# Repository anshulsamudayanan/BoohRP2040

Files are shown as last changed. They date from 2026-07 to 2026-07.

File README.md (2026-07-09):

# Booh RP2040

A minimal, RP2040-based Pi Pico clone, designed and built from scratch in KiCad.



## Overview

Booh RP2040 is a custom development board built around the Raspberry Pi RP2040 microcontroller.This repo covers schematic capture, PCB layout, and assembly for a minimal Pico-style board.

## Specs

- **MCU:** Raspberry Pi RP204
- **Flash:** W25Q16JV, 2MB QSPI flash
- **Power:** USB-C input, regulated to 3.3V via onboard LDO
- **I/O:** through-hole pin headers along both edges
- **Layout:** 2-layer PCB with groud layer
- **Form factor:** Pi Pico-sized footprint

## Repo Contents

- `kicad/` — KiCad schematic and PCB layout files
- `gerbers/` — Gerber files for manufacturing
- `bom/` — Bill of materials

## Getting Started

1. Order the PCB using the Gerber files in `gerbers/` (JLCPCB, PCBWay, etc.)
2. Source components using the BOM in `bom/`
3. Assemble and Solder by hand to obtain new skillz
4. Flash with MicroPython, CircuitPython, or the Pico SDK like a standard RP2040 board

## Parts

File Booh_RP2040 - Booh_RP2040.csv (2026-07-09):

Id | Designator | Footprint | Quantity | Designation | Supplier and ref
1 | C1, C2, C3, C4, C5, C6, C7, C8, C10, C11, C17 | C_0402_1005Metric | 11 | 0.1uF | Aliexpress
2 | C9, C12 | C_0402_1005Metric | 2 | 1uF | Aliexpress
3 | C13, C14 | C_0603_1608Metric | 2 | 10uF | Aliexpress
4 | C15, C16 | C_0402_1005Metric | 2 | 15pF | Aliexpress
5 | J1 | USB_C_Receptacle_HRO_TYPE-C-31-M-12 | 1 | USB_C_Receptacle_USB2.0_14P | Aliexpress
6 | J2, J3 | PinHeader_1x20_P2.54mm_Vertical | 2 | Conn_01x20 | Aliexpress
7 | J4 | PinHeader_1x03_P2.54mm_Vertical | 1 | Conn_01x03 | Aliexpress
8 | R1, R2 | R_0402_1005Metric | 2 | 5.1K | Aliexpress
9 | R3, R4 | R_0402_1005Metric | 2 | 27K | Aliexpress
10 | R5, R6 | R_0402_1005Metric | 2 | 1K | Aliexpress
11 | R7 | R_0402_1005Metric | 1 | 10K | Aliexpress
12 | SW1 | SW_Push_SPST_NO_Alps_SKRK | 1 | SW_Push | Aliexpress
13 | U1 | QFN-56-1EP_7x7mm_P0.4mm_EP3.2x3.2mm | 1 | RP2040 | Aliexpress
14 | U3 | Winbond_USON-8-1EP_3x2mm_P0.5mm_EP0.2x1.6mm | 1 | W25Q128JVS | Aliexpress
15 | U4 | SOT-23 | 1 | MCP1700x-330xxTT | Aliexpress
16 | Y1 | Crystal_SMD_3225-4Pin_3.2x2.5mm | 1 | 12 MHz | Aliexpress
17 | - | Solder Iron | 1 | Pinecil V1 | Aliexpress
18 | - | Flux Paste | 1 | Flux Paste | Aliexpress
19 | - | Brass Sponge | 1 | to Clean | Aliexpress
20 | - | Solder Wire | 1 | wire | Aliexpress
21 | - | PCB | 1 | PCB | pcbway

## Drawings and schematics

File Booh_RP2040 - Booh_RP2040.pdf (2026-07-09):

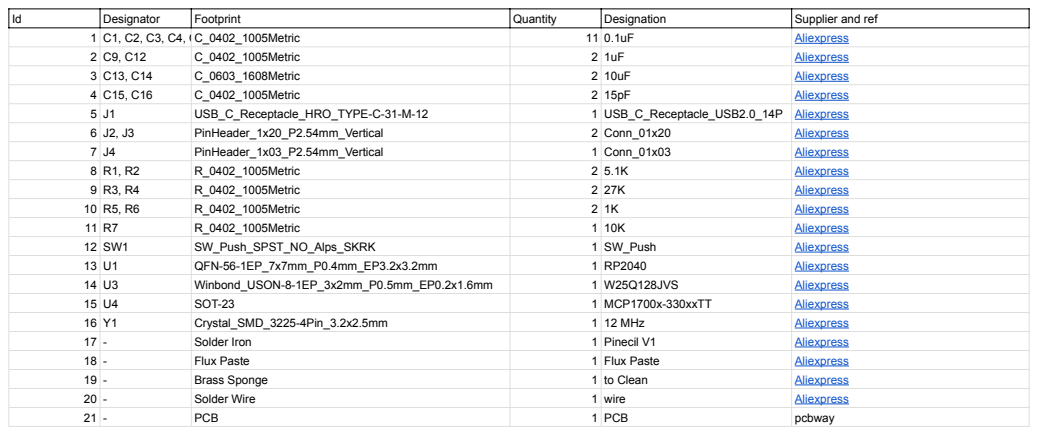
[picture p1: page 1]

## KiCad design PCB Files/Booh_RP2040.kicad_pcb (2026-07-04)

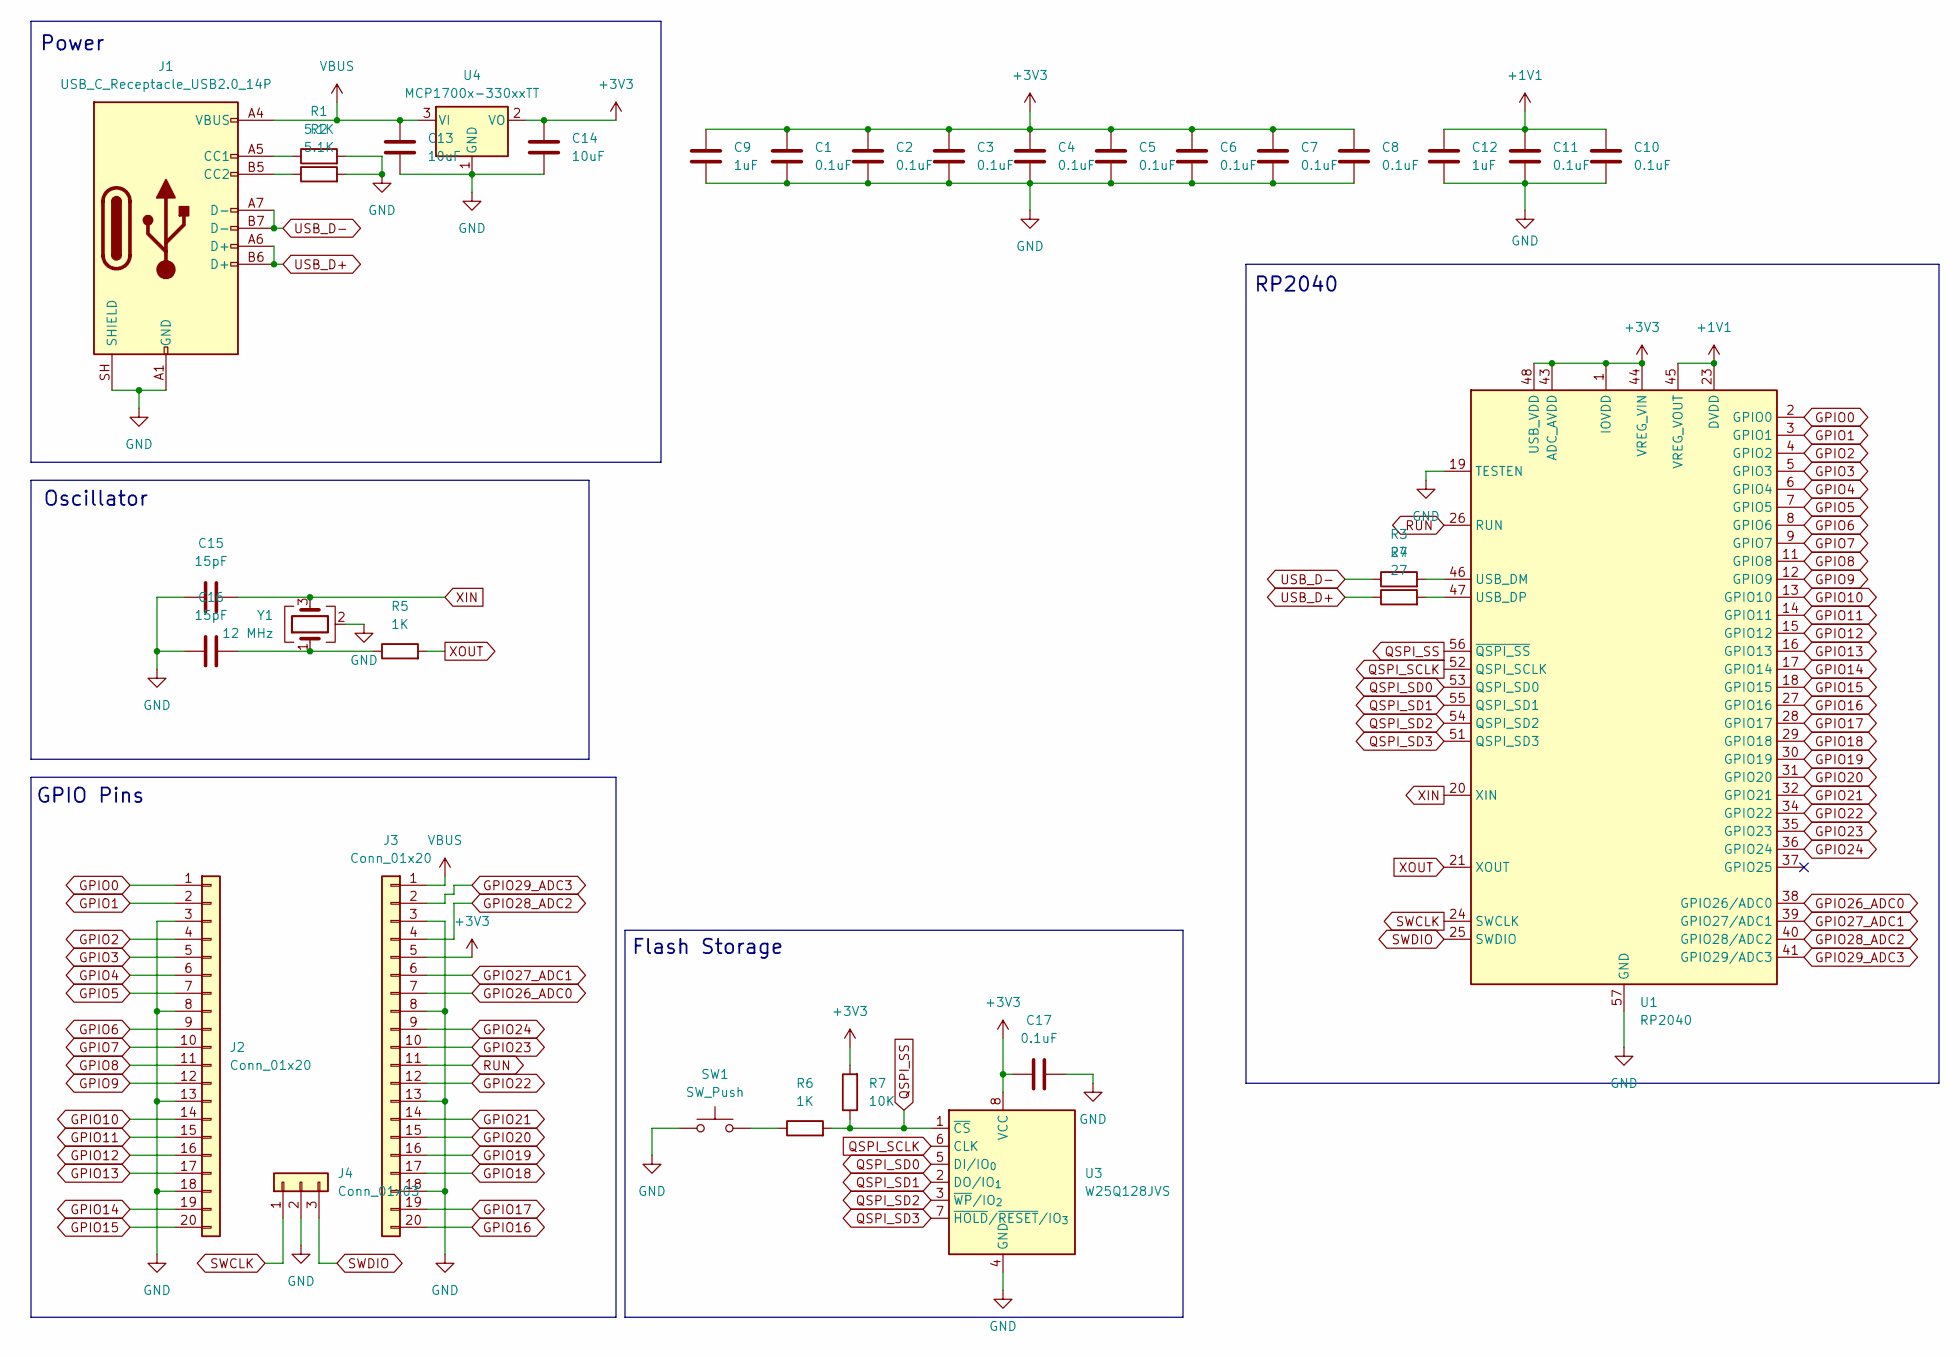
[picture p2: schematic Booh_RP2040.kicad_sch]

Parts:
C1, C2, C3, C4, C5, C6, C7, C8, C10, C11, C17: 0.1uF; C_0402_1005Metric
C9, C12: 1uF; C_0402_1005Metric
C13, C14: 10uF; C_0603_1608Metric
C15, C16: 15pF; C_0402_1005Metric
J1: USB_C_Receptacle_USB2.0_14P; USB_C_Receptacle_HRO_TYPE-C-31-M-12
J2, J3: Conn_01x20; PinHeader_1x20_P2.54mm_Vertical
J4: Conn_01x03; PinHeader_1x03_P2.54mm_Vertical
R1, R2: 5.1K; R_0402_1005Metric
R3, R4: 27; R_0402_1005Metric
R5, R6: 1K; R_0402_1005Metric
R7: 10K; R_0402_1005Metric
SW1: SW_Push; SW_Push_SPST_NO_Alps_SKRK
U1: RP2040; QFN-56-1EP_7x7mm_P0.4mm_EP3.2x3.2mm
U3: W25Q128JVS; Winbond_USON-8-1EP_3x2mm_P0.5mm_EP0.2x1.6mm
U4: MCP1700x-330xxTT; SOT-23
Y1: 12 MHz; Crystal_SMD_3225-4Pin_3.2x2.5mm

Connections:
+1V1: C10.1, C11.1, C12.1, U1.23 (DVDD), U1.45 (VREG_VOUT), U1.50 (DVDD)
+3V3: C1.1, C2.1, C3.1, C4.1, C5.1, C6.1, C7.1, C8.1, C9.1, C14.1, C17.1, J3.5, R7.2, U1.1 (IOVDD), U1.10 (IOVDD), U1.22 (IOVDD), U1.33 (IOVDD), U1.42 (IOVDD), U1.43 (ADC_AVDD), U1.44 (VREG_VIN), U1.48 (USB_VDD), U1.49 (IOVDD), U3.8 (VCC), U4.2 (VO)
GND: C1.2, C2.2, C3.2, C4.2, C5.2, C6.2, C7.2, C8.2, C9.2, C10.2, C11.2, C12.2, C13.2, C14.2, C15.1, C16.1, C17.2, J1.A1 (GND), J1.A12 (GND), J1.B1 (GND), J1.B12 (GND), J1.SH (SHIELD), J2.3, J2.8, J2.13, J2.18, J3.3, J3.8, J3.13, J3.18, J4.2, R1.2, R2.2, SW1.1, U1.19 (TESTEN), U1.57 (GND), U3.4 (GND), U4.1 (GND), Y1.2 (G), Y1.4 (G)
GPIO0: J2.1, U1.2 (GPIO0)
GPIO1: J2.2, U1.3 (GPIO1)
GPIO2: J2.4, U1.4 (GPIO2)
GPIO3: J2.5, U1.5 (GPIO3)
GPIO4: J2.6, U1.6 (GPIO4)
GPIO5: J2.7, U1.7 (GPIO5)
GPIO6: J2.9, U1.8 (GPIO6)
GPIO7: J2.10, U1.9 (GPIO7)
GPIO8: J2.11, U1.11 (GPIO8)
GPIO9: J2.12, U1.12 (GPIO9)
GPIO10: J2.14, U1.13 (GPIO10)
GPIO11: J2.15, U1.14 (GPIO11)
GPIO12: J2.16, U1.15 (GPIO12)
GPIO13: J2.17, U1.16 (GPIO13)
GPIO14: J2.19, U1.17 (GPIO14)
GPIO15: J2.20, U1.18 (GPIO15)
GPIO16: J3.20, U1.27 (GPIO16)
GPIO17: J3.19, U1.28 (GPIO17)
GPIO18: J3.17, U1.29 (GPIO18)
GPIO19: J3.16, U1.30 (GPIO19)
GPIO20: J3.15, U1.31 (GPIO20)
GPIO21: J3.14, U1.32 (GPIO21)
GPIO22: J3.12, U1.34 (GPIO22)
GPIO23: J3.10, U1.35 (GPIO23)
GPIO24: J3.9, U1.36 (GPIO24)
GPIO26_ADC0: J3.7, U1.38 (GPIO26/ADC0)
GPIO27_ADC1: J3.6, U1.39 (GPIO27/ADC1)
GPIO28_ADC2: J3.4, U1.40 (GPIO28/ADC2)
GPIO29_ADC3: J3.2, U1.41 (GPIO29/ADC3)
unnamed: C16.2, R5.1, Y1.1
unnamed: J1.A5 (CC1), R1.1
unnamed: J1.B5 (CC2), R2.1
unnamed: R6.1, SW1.2
unnamed: R3.2, U1.46 (USB_DM)
unnamed: R4.2, U1.47 (USB_DP)
QSPI_SCLK: U1.52 (QSPI_SCLK), U3.6 (CLK)
QSPI_SD0: U1.53 (QSPI_SD0), U3.5 (DI/IO_{0})
QSPI_SD1: U1.55 (QSPI_SD1), U3.2 (DO/IO_{1})
QSPI_SD2: U1.54 (QSPI_SD2), U3.3 (~WP/IO_{2})
QSPI_SD3: U1.51 (QSPI_SD3), U3.7 (~HOLD/~RESET/IO_{3})
QSPI_SS: R6.2, R7.1, U1.56 (~QSPI_SS), U3.1 (~CS)
RUN: J3.11, U1.26 (RUN)
SWCLK: J4.1, U1.24 (SWCLK)
SWDIO: J4.3, U1.25 (SWDIO)
USB_D+: J1.A6 (D+), J1.B6 (D+), R4.1
USB_D-: J1.A7 (D-), J1.B7 (D-), R3.1
VBUS: C13.1, J1.A4 (VBUS), J1.A9 (VBUS), J1.B4 (VBUS), J1.B9 (VBUS), J3.1, U4.3 (VI)
XIN: C15.2, U1.20 (XIN), Y1.3
XOUT: R5.2, U1.21 (XOUT)

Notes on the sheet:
Oscillator
GPIO Pins
RP2040
Flash Storage
Power

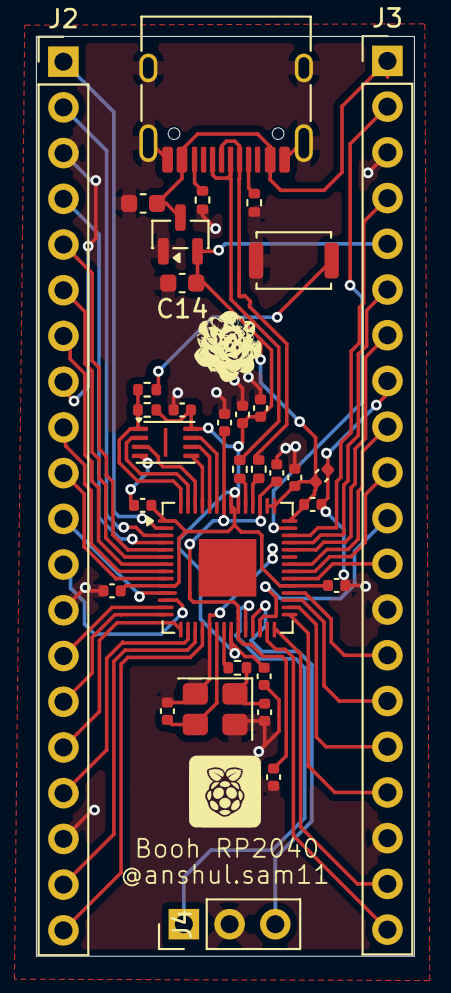
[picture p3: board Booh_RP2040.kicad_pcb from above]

Board: 2 copper layers, 21.0 x 51.1 mm, 33 parts (0 on the bottom side), 52 nets.
